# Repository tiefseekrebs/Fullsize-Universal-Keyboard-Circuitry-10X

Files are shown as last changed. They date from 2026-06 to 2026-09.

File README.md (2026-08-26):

# FUKC10X — Fullsize Universal Keyboard Circuitry 10X

> 🚧 **Work in Progress** — This PCB has **not yet been prototyped** and currently has **no firmware**.
---

## Introduction

**Fullsize Universal Keyboard Circuitry 10X or fukc10X for short**, is an open-source, full-size (100%) mechanical keyboard PCB designed in KiCad. It's essentially a Daughterboard only h87 footprint pcb just with a numpad attached.

This came to life after i wanted to design a Fullsize Keyboard but found out there were no modern opensource full-size keyboard pcbs.

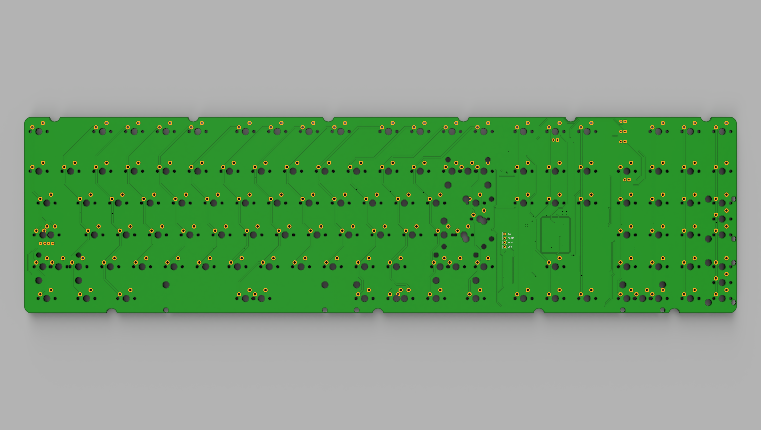
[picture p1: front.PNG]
Render Front

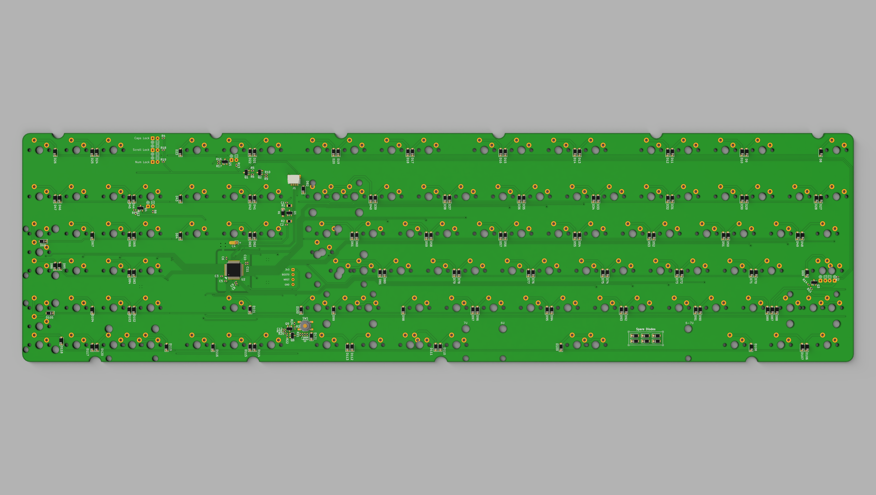
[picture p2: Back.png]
Render Back


---

## Features
- Dual Indicators. You can have indicator leds for Caps Lock, Scroll Lock and Num Lock directly at the switches for the use with windowed Keycaps and above the numpad in a small cluster.
- Decent layout support with ANSI+ISO Enter, split l-Shift, split r-Shift, split Backspace, split numpad Enter, split numpad plus and split numpad minus (just check the diagramm)
- Supported bottomrows are Tsangan **7U** aswell as **6U** bottom row, like the Realforce R1 87U. (*I will not be adding 6.25u bottom row*)

---

##  Design Files

The files were designed in KiCAD 10.0.
This project uses component symbols and footprints from [AlexandriaLibrary](https://github.com/AcheronProject/AlexandriaLibrary) by AcheronProject, licensed under the BSD-3-Clause License.
Furthermore some symbols and footprints from the [marbastlib](https://github.com/ebastler/marbastlib) are used.

---

## Supported Layouts

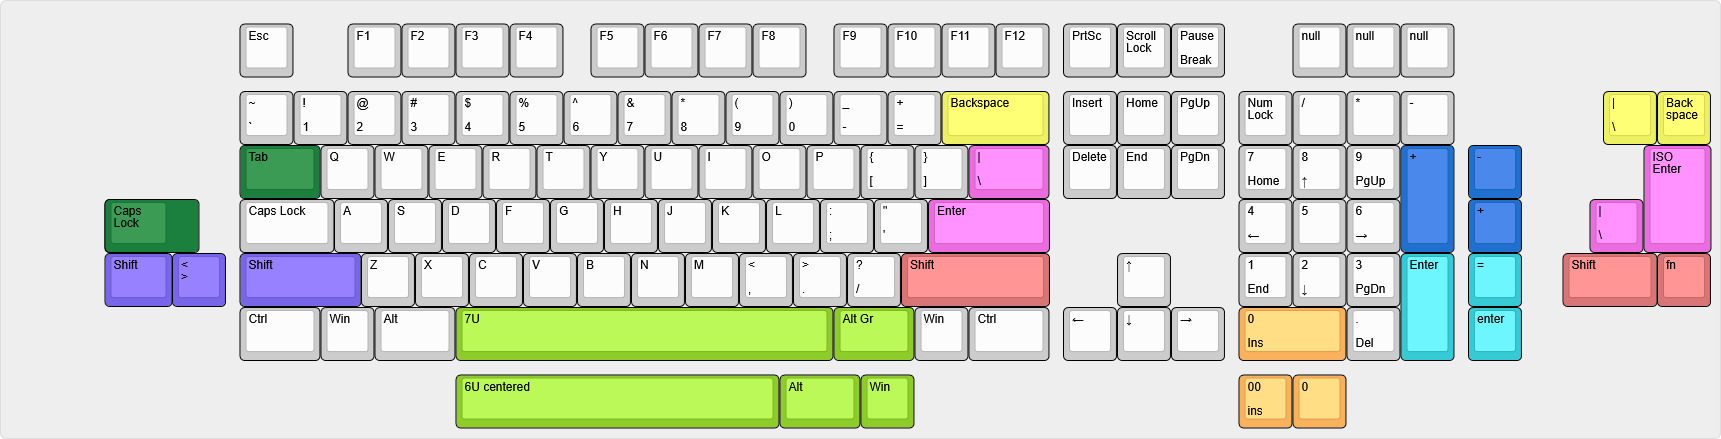
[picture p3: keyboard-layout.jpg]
KLE Layout


---

## Daughterboard Connector

Uses standard 4-pin JST commonly found on all sorts of Keyboard PCBs. Compatible with any daughterboard that follows the [ai03 unified daughterboard standard](https://unified-daughterboard.github.io/#/) pinout.

---

## Firmware

> ⚠️ **Firmware is not yet written.**

| Firmware | Status |
|---|---|
| **[QMK](https://qmk.fm/)** | Planned after i get Prototypes. |
| **[VIAL](https://get.vial.today/)** | Planned after i get Prototypes. |
| **[VIA](https://www.caniusevia.com/)** | Maybe? |

---

## License

This project is licensed under **Creative Commons Attribution-ShareAlike 4.0 International** ([CC BY-SA 4.0](https://creativecommons.org/licenses/by-sa/4.0/deed.en)).
You may share and adapt it, including commercially, with proper attribution.
Modified versions must be distributed under the same license.

---

*This README was written with the help of deepseek-v4-pro because i suck at stuff like this.*

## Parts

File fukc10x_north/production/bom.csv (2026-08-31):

Designator | Footprint | Quantity | Value | LCSC Part #
C1, C2 | 0402 | 2 | 1uF | C52923
C10, C3, C5, C6 | 0402 | 4 | 100n
C11, C8 | 0402 | 2 | 4.7u
C12 | 0402 | 1 | 100nF | C52923
C4 | CP_EIA-3216-10_Kemet-I_Pad1.58x1.35mm_HandSolder | 1 | 10u
C7 | 0402 | 1 | 10uF | C52923
C9 | 0402 | 1 | 10n
D1 | D_SOD-123 | 1 | B5819W-SL
D10, D100, D101, D102, D103, D104, D105, D106, D107, D108, D109, D11, D110, D111, D112, D113, D114, D115, D116, D117, D118, D119, D12, D120, D13, D14, D15, D16, D17, D18, D19, D2, D20, D21, D22, D23, D24, D25, D26, D27, D28, D29, D3, D30, D31, D32, D33, D34, D35, D36, D37, D38, D39, D4, D40, D41, D42, D43, D44, D45, D46, D47, D48, D49, D5, D50, D51, D52, D53, D54, D55, D56, D57, D58, D59, D6, D60, D61, D62, D63, D64, D65, D66, D67, D68, D69, D7, D70, D71, D72, D73, D74, D75, D76, D77, D78, D79, D8, D80, D81, D82, D83, D84, D85, D86, D87, D88, D89, D9, D90, D91, D92, D93, D94, D95, D96, D97, D98, D99 | D_SOD-123 | 119 | 1N4148W | C81598
D121 | D_SOD-123 | 1 | 1N4148
J1 | JST_SH_SM04B-SRSS-TB_1x04-1MP_P1.00mm_Horizontal | 1 | SM04B-SRSS-TB | C160404
J9 | PinHeader_1x4_P2.54mm_Vertical | 1 | Conn_01x04_Pin
Q1 | SOT-23 | 1 | AO3401A
Q2, Q3, Q4, Q5, Q8, Q9 | SOT-23 | 6 | 2N7002
R1, R2 | 0805 | 2 | 100k
R10, R14, R15, R17, R21, R24, R25, R5 | 0402 | 8 | 10k
R11, R12, R16, R26, R6, R9 | 0402 | 6 | 100
R13, R18, R19, R23, R4, R7, R8 | 0402 | 7 | 1k
R20 | 0402 | 1 | 1M
R22 | 0402 | 1 | 100k
R3 | 0402 | 1 | 330k
SW1 | SW_SPST_TL3342 | 1 | SW_SPST
U1 | SOT-23 | 1 | XC6206P332MR | C5446
U2 | LQFP-48_7x7mm_P0.5mm | 1 | STM32F072CBT6 | C81720

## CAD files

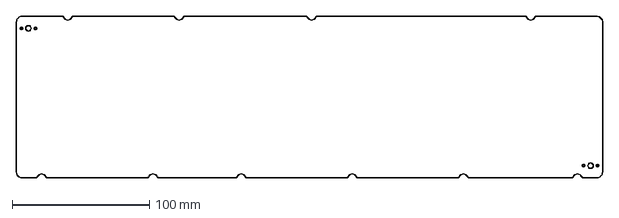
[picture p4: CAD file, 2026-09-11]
fukc10x_north/outline.dxf
427.1 x 117.5 mm

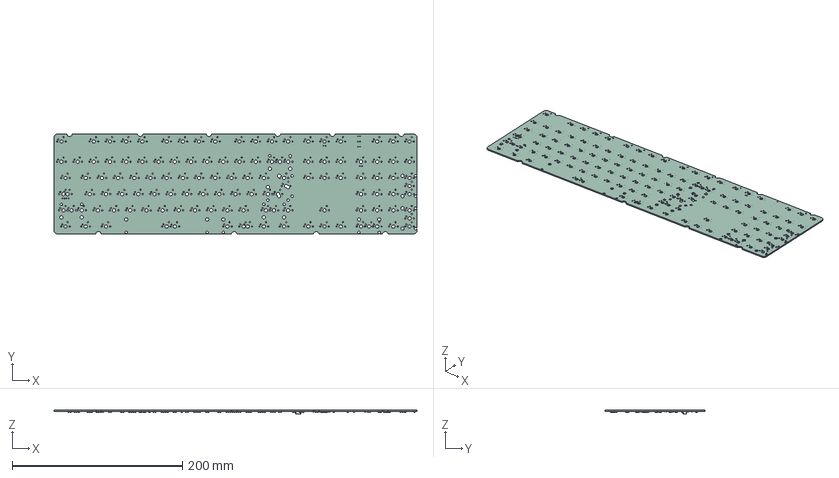
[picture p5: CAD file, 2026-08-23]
fukc10x_north/fukc10X_north.step
427.1 x 117.5 x 4.56 mm
D_SOD-123 x 120
TSOT-23 x 5
R_0402_1005Metric x 15
SW_SPST_TL3342 x 2
C_0402_1005Metric x 10
JST_SH_SM04B-SRSS-TB_1x04-1MP_P1.00mm_Horizontal
SOT-23
CP_EIA-3216-10_Kemet-I
LQFP-48_7x7mm_P0.5mm
R_0805_2012Metric x 2
fukc10x_north_PCB

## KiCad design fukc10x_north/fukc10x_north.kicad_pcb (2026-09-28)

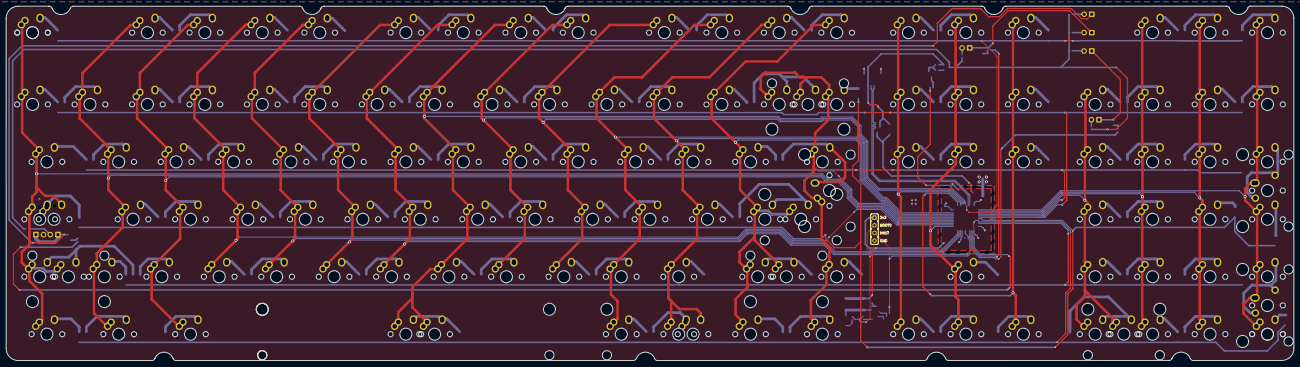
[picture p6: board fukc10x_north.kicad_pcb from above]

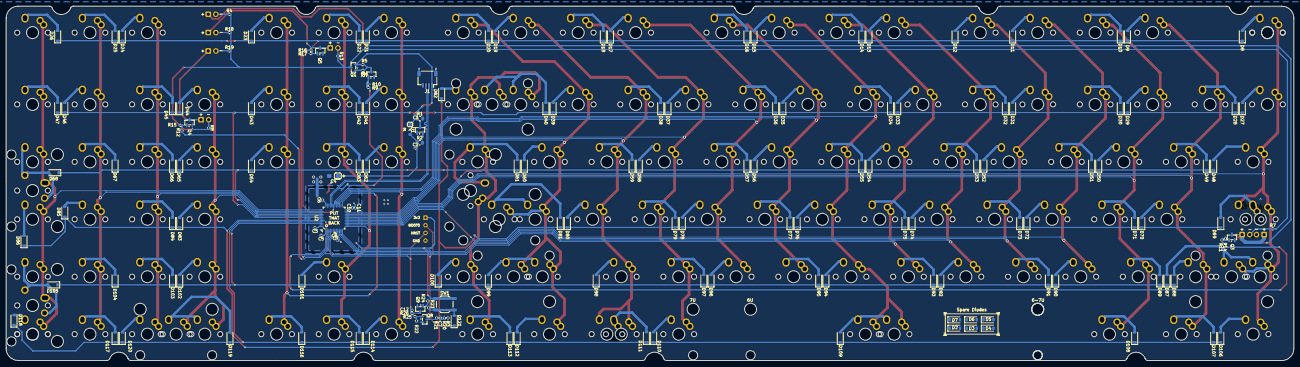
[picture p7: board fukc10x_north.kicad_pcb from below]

Board: 2 copper layers, 427.1 x 117.5 mm, 305 parts (170 on the bottom side), 173 nets.

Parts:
C1, C2: 1uF; C_0402_1005Metric
C3, C5, C6, C10: 100n; C_0402_1005Metric
C4: 10u; CP_EIA-3216-10_Kemet-I_Pad1.58x1.35mm_HandSolder
C7: 10uF; C_0402_1005Metric
C8, C11: 4.7u; C_0402_1005Metric
C9: 10n; C_0402_1005Metric
C12: 100nF; C_0402_1005Metric
D1: B5819W-SL; D_SOD-123
D2, D3, D4, D5, D6, D7, D8, D9, D10, D11, D12, D13, D14, D15, D16, D17, D18, D19, D20, D21, D22, D23, D24, D25, D26, D27, D28, D29, D30, D31, D32, D33, D34, D35, D36, D37, D38, D39, D40, D41, D42, D43, D44, D45, D46, D47, D48, D49, D50, D51, D52, D53, D54, D55, D56, D57, D58, D59, D60, D61, D62, D63, D64, D65, D66, D67, D68, D69, D70, D71, D72, D73, D74, D75, D76, D77, D78, D79, D80, D81, D82, D83, D84, D85, D86, D87, D88, D89, D90, D91, D92, D93, D94, D95, D96, D97, D98, D99, D100, D101, D102, D103, D104, D105, D106, D107, D108, D109, D110, D111, D112, D113, D114, D115, D116, D117, D118, D119, D120: 1N4148W; D_SOD-123
D121: 1N4148; D_SOD-123
J1: SM04B-SRSS-TB; JST_SH_SM04B-SRSS-TB_1x04-1MP_P1.00mm_Horizontal
J2, J3, J4, J5, J8: LED_Conn01x02_Pin; LED_MX_3mm
J6: LED_Conn01x02_Pin; LED_MX_3mm-ROT
J7: LED; LED_MX_3mm
J9: Conn_01x04_Pin; PinHeader_1x4_P2.54mm_Vertical
MX1, MX2, MX3, MX4, MX5, MX6, MX7, MX8, MX9, MX10, MX11, MX12, MX13, MX14, MX15, MX16, MX17, MX18, MX19, MX20, MX21, MX22, MX23, MX24, MX25, MX26, MX27, MX28, MX29, MX30, MX31, MX32, MX33, MX35, MX36, MX37, MX38, MX39, MX40, MX41, MX43, MX44, MX45, MX46, MX47, MX48, MX49, MX50, MX51, MX52, MX53, MX54, MX57, MX58, MX59, MX60, MX61, MX62, MX64, MX67, MX68, MX69, MX70, MX71, MX72, MX73, MX74, MX75, MX76, MX77, MX78, MX80, MX81, MX82, MX83, MX84, MX87, MX88, MX89, MX90, MX91, MX92, MX93, MX94, MX95, MX96, MX97, MX100, MX101, MX102, MX103, MX104, MX106, MX108, MX114, MX115, MX117, MX118, MX119, MX121, MX122, MX123, MX124: MX_SW_solder; MXA100
MX34: MX_SW_solder; MXA250
MX42, MX55, MX107, MX109, MX112, MX113, MX116: MX_SW_solder; MXA150
MX56: MX_SW_solder; MXA_ISO_Enter
MX63, MX105: MX_SW_solder; MX200V
MX65, MX98: MX_SW_solder; MXA175
MX66, MX86: MX_SW_solder; MXA125
MX79: MX_SW_solder; MXA225R
MX85: MX_SW_solder; MXA225
MX99: MX_SW_solder; MXA275
MX110: MX_SW_solder; MXA600R
MX111: MX_SW_solder; MXA700R
MX120: MX_SW_solder; MXA200R
MX125: alps capslock 1.5u; SW_Alps_1.75u_STP_1.5
MX126, MX127: MX_SW_solder; SW_Alps_1u
Q1: AO3401A; SOT-23
Q2, Q3, Q4, Q5, Q8, Q9: 2N7002; SOT-23
R1, R2: 100k; R_0805_2012Metric
R3: 330k; R_0402_1005Metric
R4, R7, R8, R13, R18, R19, R23: 1k; R_0402_1005Metric
R5, R10, R14, R15, R17, R21, R24, R25: 10k; R_0402_1005Metric
R6, R9, R11, R12, R16, R26: 100; R_0402_1005Metric
R20: 1M; R_0402_1005Metric
R22: 100k; R_0402_1005Metric
SW1: SW_SPST; SW_SPST_TL3342
U1: XC6206P332MR; SOT-23
U2: STM32F072CBT6; LQFP-48_7x7mm_P0.5mm

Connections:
+3V3: C2.2, C3.1, C4.1, C5.1, C6.1, C8.2, C9.2, C10.2, C11.1, D1.2 (A), J9.1, R2.1, SW1.1 (A), U1.2 (VO), U2.1 (VBAT), U2.9 (VDDA), U2.24 (VDD), U2.36 (VDDIO2), U2.48 (VDD)
+5V: C1.1, D1.1 (K), J1.1, Q1.2 (S), R1.1, R5.2, U1.3 (VI)
BOOT0: C7.1, J9.2, R3.2, R20.1, R21.1, U2.44 (BOOT0)
COL0: MX1.2, MX20.2, MX42.2, MX65.1, MX66.2, MX85.2, MX86.2, MX107.2, MX125.2, U2.17 (PA7/TIM3_CH2/TIM14_CH1/ADC_IN7)
COL1: MX2.2, MX21.2, MX43.2, MX67.2, MX87.2, MX108.2, U2.16 (PA6/ADC_IN6/TIM3_CH1/TIM16_CH1)
COL2: MX3.2, MX22.2, MX44.2, MX68.2, MX88.2, MX109.2, U2.15 (PA5/ADC_IN5/DAC_OUT2)
COL3: MX4.2, MX23.2, MX45.2, MX69.2, MX89.2, U2.14 (PA4/TIM14_CH1/ADC_IN4)
COL4: MX5.2, MX24.2, MX46.2, MX70.2, MX90.2, U2.12 (PA2/ADC_IN2)
COL5: MX6.2, MX25.2, MX47.2, MX71.2, MX91.2, U2.11 (PA1/ADC_IN1)
COL6: MX7.2, MX26.2, MX48.2, MX72.2, MX92.2, U2.10 (PA0/ADC_IN0)
COL7: MX8.2, MX27.2, MX49.2, MX73.2, MX93.2, MX110.2, MX111.2, U2.29 (TIM1_CH1/PA8)
COL8: MX9.2, MX28.2, MX50.2, MX74.2, MX94.2, U2.28 (SPI2_MOSI/I2S2_SD/PB15)
COL9: MX10.2, MX29.2, MX51.2, MX75.2, MX95.2, U2.22 (PB11/TIM2_CH4/I2C2_SDA)
COL10: MX11.2, MX30.2, MX52.2, MX76.2, MX96.2, MX112.2, U2.21 (PB10/SPI2_SCK/I2C2_SCL/TIM2_CH3)
COL11: MX12.2, MX31.2, MX53.2, MX77.2, MX97.2, MX113.2, MX114.1, U2.20 (PB2)
COL12: MX13.2, MX32.2, MX54.2, MX78.2, MX79.2, MX98.2, MX99.2, MX115.2, U2.19 (PB1/TIM3_CH4/TIM14_CH1/ADC_IN9)
COL13: MX33.2, MX34.2, MX55.2, MX56.2, MX80.2, MX100.2, MX116.2, U2.18 (PB0/TIM3_CH3/ADC_IN8)
COL14: MX14.2, MX35.2, MX57.2, MX117.2, U2.27 (SPI2_MISO/I2S2_MCK/I2C2_SDA/TIM15_CH1/P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)
COL15: MX15.2, MX36.2, MX58.2, MX101.2, MX118.2, U2.13 (PA3/TIM15_CH2/ADC_IN3)
COL16: MX16.2, MX37.2, MX59.2, MX119.2, U2.25 (PB12)
COL17: MX38.2, MX60.2, MX81.2, MX102.2, MX120.2, MX123.2, U2.40 (SPI1_MISO/I2S1_MCK/TIM3_CH1/PB4)
COL18: MX17.2, MX39.2, MX61.2, MX82.2, MX103.2, MX124.2, U2.39 (SPI1_SCK/I2S1_CK/TIM2_CH2/PB3)
COL19: MX18.2, MX40.2, MX62.2, MX83.2, MX104.2, MX121.2, U2.38 (PA15)
COL20: MX19.2, MX41.2, MX63.2, MX64.2, MX84.2, MX105.2, MX106.2, MX122.2, MX126.2, MX127.2, U2.37 (SWCLK/PA14)
D+: J1.3, U2.33 (USB_DP/PA12)
D-: J1.2, U2.32 (USB_DM/TIM1_CH4/PA11)
GND: C1.2, C2.1, C3.2, C4.2, C5.2, C6.2, C7.2, C8.1, C9.1, C10.1, C11.2, C12.2, J1.4, J1.MP (MountPin), J9.4, Q2.2 (S), Q3.2 (S), Q4.2 (S), Q5.2 (S), Q8.2 (S), Q9.2 (S), R1.2, R2.2, R10.1, R14.1, R15.1, R17.1, R20.2, R22.2, R24.1, U1.1 (GND), U2.8 (VSSA), U2.23 (VSS), U2.35 (VSS), U2.47 (VSS)
LED_PWM: R9.1, U2.30 (TIM1_CH2/PA9)
LED_PWM_OUT: Q1.3 (D), R4.2, R7.2, R8.2, R13.2, R18.2, R19.2
LedCaps: R11.1, U2.2 (PC13)
LedNum: R12.1, U2.4 (PC15/OSC32_OUT)
LedScroll: R16.1, U2.3 (PC14/OSC32_IN)
NRST: C12.1, J9.3, R26.2, U2.7 (NRST)
unnamed: D8.2 (A), MX1.1
unnamed: D9.2 (A), MX2.1
unnamed: D10.2 (A), MX3.1
unnamed: D11.2 (A), MX4.1
unnamed: D12.2 (A), MX5.1
unnamed: D13.2 (A), MX6.1
unnamed: D14.2 (A), MX7.1
unnamed: D15.2 (A), MX8.1
unnamed: D16.2 (A), MX9.1
unnamed: D17.2 (A), MX10.1
unnamed: D18.2 (A), MX11.1
unnamed: D19.2 (A), MX12.1
unnamed: D20.2 (A), MX13.1
unnamed: D21.2 (A), MX14.1
unnamed: D22.2 (A), MX15.1
unnamed: D23.2 (A), MX16.1
unnamed: D24.2 (A), MX17.1
unnamed: D25.2 (A), MX18.1
unnamed: D26.2 (A), MX19.1
unnamed: D27.2 (A), MX20.1
unnamed: D28.2 (A), MX21.1
unnamed: D29.2 (A), MX22.1
unnamed: D30.2 (A), MX23.1
unnamed: D31.2 (A), MX24.1
unnamed: D32.2 (A), MX25.1
unnamed: D33.2 (A), MX26.1
unnamed: D34.2 (A), MX27.1
unnamed: D35.2 (A), MX28.1
unnamed: D36.2 (A), MX29.1
unnamed: D37.2 (A), MX30.1
unnamed: D38.2 (A), MX31.1
unnamed: D39.2 (A), MX32.1
unnamed: D40.2 (A), MX33.1, MX34.1
unnamed: D41.2 (A), MX35.1
unnamed: D42.2 (A), MX36.1
unnamed: D43.2 (A), MX37.1
unnamed: D44.2 (A), MX38.1
unnamed: D45.2 (A), MX39.1
unnamed: D46.2 (A), MX40.1
unnamed: D47.2 (A), MX41.1
unnamed: D48.2 (A), MX42.1
unnamed: D49.2 (A), MX43.1
unnamed: D50.2 (A), MX44.1
unnamed: D51.2 (A), MX45.1
unnamed: D52.2 (A), MX46.1
unnamed: D53.2 (A), MX47.1
unnamed: D54.2 (A), MX48.1
unnamed: D55.2 (A), MX49.1
unnamed: D56.2 (A), MX50.1
unnamed: D57.2 (A), MX51.1
unnamed: D58.2 (A), MX52.1
unnamed: D59.2 (A), MX53.1
unnamed: D60.2 (A), MX54.1
unnamed: D61.2 (A), MX55.1, MX56.1
unnamed: D62.2 (A), MX57.1
unnamed: D63.2 (A), MX58.1
unnamed: D64.2 (A), MX59.1
unnamed: D65.2 (A), MX60.1
unnamed: D66.2 (A), MX61.1
unnamed: D67.2 (A), MX62.1
unnamed: D68.2 (A), MX63.1, MX64.1, MX126.1
unnamed: D69.2 (A), MX65.2, MX66.1, MX125.1
unnamed: D70.2 (A), MX67.1
unnamed: D71.2 (A), MX68.1
unnamed: D72.2 (A), MX69.1
unnamed: D73.2 (A), MX70.1
unnamed: D74.2 (A), MX71.1
unnamed: D75.2 (A), MX72.1
unnamed: D76.2 (A), MX73.1
unnamed: D77.2 (A), MX74.1
unnamed: D78.2 (A), MX75.1
unnamed: D79.2 (A), MX76.1
unnamed: D80.2 (A), MX77.1
unnamed: D81.2 (A), MX78.1, MX79.1
unnamed: D82.2 (A), MX80.1
unnamed: D83.2 (A), MX81.1
unnamed: D84.2 (A), MX82.1
unnamed: D85.2 (A), MX83.1
unnamed: D86.2 (A), MX84.1
unnamed: D87.2 (A), MX85.1, MX86.1
unnamed: D88.2 (A), MX87.1
unnamed: D89.2 (A), MX88.1
unnamed: D90.2 (A), MX89.1
unnamed: D91.2 (A), MX90.1
unnamed: D92.2 (A), MX91.1
unnamed: D93.2 (A), MX92.1
unnamed: D94.2 (A), MX93.1
unnamed: D95.2 (A), MX94.1
unnamed: D96.2 (A), MX95.1
unnamed: D97.2 (A), MX96.1
unnamed: D98.2 (A), MX97.1
unnamed: D99.2 (A), MX98.1, MX99.1
unnamed: D100.2 (A), MX100.1
unnamed: D101.2 (A), MX101.1
unnamed: D102.2 (A), MX102.1
unnamed: D103.2 (A), MX103.1
unnamed: D104.2 (A), MX104.1
unnamed: D105.2 (A), MX105.1, MX106.1, MX127.1
unnamed: D106.2 (A), MX107.1
unnamed: D107.2 (A), MX108.1
unnamed: D108.2 (A), MX109.1
unnamed: D109.2 (A), MX110.1, MX111.1
unnamed: D110.2 (A), MX112.1
unnamed: D111.2 (A), MX113.1, MX114.2
unnamed: D112.2 (A), MX115.1
unnamed: D113.2 (A), MX116.1
unnamed: D114.2 (A), MX117.1
unnamed: D115.2 (A), MX118.1
unnamed: D116.2 (A), MX119.1
unnamed: D117.2 (A), MX121.1
unnamed: D118.2 (A), MX122.1
unnamed: D119.2 (A), MX120.1, MX123.1
unnamed: D120.2 (A), MX124.1
unnamed: D121.2 (A), R23.2, SW1.2 (B)
unnamed: D121.1 (K), R3.1
unnamed: J2.2 (A), R4.1
unnamed: J2.1 (K), J6.1 (K), J7.1 (K), Q3.3 (D)
unnamed: J3.2 (A), R18.1
unnamed: J3.1 (K), J8.1 (K), Q5.3 (D)
unnamed: J4.2 (A), R19.1
unnamed: J4.1 (K), J5.1 (K), Q4.3 (D)
unnamed: J5.2 (A), R8.1
unnamed: J6.2 (A), J7.2 (A), R7.1
unnamed: J8.2 (A), R13.1
unnamed: Q1.1 (G), R6.2
unnamed: Q2.3 (D), R5.1, R6.1
unnamed: Q2.1 (G), R9.2, R10.2
unnamed: Q3.1 (G), R11.2, R14.2
unnamed: Q4.1 (G), R12.2, R15.2
unnamed: Q5.1 (G), R16.2, R17.2
unnamed: Q8.3 (D), R21.2
unnamed: Q8.1 (G), R22.1, R25.1
unnamed: Q9.3 (D), R25.2, R26.1
unnamed: Q9.1 (G), R23.1, R24.2
ROW0: D8.1 (K), D9.1 (K), D10.1 (K), D11.1 (K), D12.1 (K), D13.1 (K), D14.1 (K), D15.1 (K), D16.1 (K), D17.1 (K), D18.1 (K), D19.1 (K), D20.1 (K), D21.1 (K), D22.1 (K), D23.1 (K), D24.1 (K), D25.1 (K), D26.1 (K), U2.31 (TIM1_CH3/PA10)
ROW1: D27.1 (K), D28.1 (K), D29.1 (K), D30.1 (K), D31.1 (K), D32.1 (K), D33.1 (K), D34.1 (K), D35.1 (K), D36.1 (K), D37.1 (K), D38.1 (K), D39.1 (K), D40.1 (K), D41.1 (K), D42.1 (K), D43.1 (K), D44.1 (K), D45.1 (K), D46.1 (K), D47.1 (K), U2.42 (I2C1_SCL/PB6)
ROW2: D48.1 (K), D49.1 (K), D50.1 (K), D51.1 (K), D52.1 (K), D53.1 (K), D54.1 (K), D55.1 (K), D56.1 (K), D57.1 (K), D58.1 (K), D59.1 (K), D60.1 (K), D61.1 (K), D62.1 (K), D63.1 (K), D64.1 (K), D65.1 (K), D66.1 (K), D67.1 (K), D68.1 (K), U2.41 (SPI1_MOSI/I2S1_SD/TIM3_CH2/PB5)
ROW3: D69.1 (K), D70.1 (K), D71.1 (K), D72.1 (K), D73.1 (K), D74.1 (K), D75.1 (K), D76.1 (K), D77.1 (K), D78.1 (K), D79.1 (K), D80.1 (K), D81.1 (K), D82.1 (K), D83.1 (K), D84.1 (K), D85.1 (K), D86.1 (K), U2.43 (2C1_SDA/PB7)
ROW4: D87.1 (K), D88.1 (K), D89.1 (K), D90.1 (K), D91.1 (K), D92.1 (K), D93.1 (K), D94.1 (K), D95.1 (K), D96.1 (K), D97.1 (K), D98.1 (K), D99.1 (K), D100.1 (K), D101.1 (K), D102.1 (K), D103.1 (K), D104.1 (K), D105.1 (K), U2.46 (SPI2_NSS/I2S2_WS/I2C1_SDA/TIM17_CH1/PB9)
ROW5: D106.1 (K), D107.1 (K), D108.1 (K), D109.1 (K), D110.1 (K), D111.1 (K), D112.1 (K), D113.1 (K), D114.1 (K), D115.1 (K), D116.1 (K), D117.1 (K), D118.1 (K), D119.1 (K), D120.1 (K), U2.45 (I2C1_SCL/TIM16_CH1/PB8)

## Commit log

2026-06-07 Add PCB files
    [FullsizeKeyboardPCB.kicad_sch, bom.csv, designators.csv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]
2026-06-07 Add PCB files again
    [FullsizeKeyboardPCB.kicad_sch, bom.csv, designators.csv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]
2026-06-07 further cleanup
    [oh10x_simple.step]
2026-06-08 Extended Matrix. Added split r-shift and split l-shift. LED support. Removed three of the 4 top right keys because ugly and to make space for indicator leds there
    [fukc10X.kicad_sch, fukc10X.step, matrix.kicad_sch]
2026-06-08 Added some Silkscreen Text aswell as spare diodes
    [fukc10X.kicad_sch, fukc10X.step]
2026-06-09 Diodes moved, ISO enter added, Som Silkscreens moved aswell. Generally some cleanup
    [matrix.kicad_sch]
2026-06-11 added split backspace + some updates to the matrix
    [bom.csv, designators.csv, fukc10X.kicad_sch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]
2026-06-13 silkscreen adjustment. 87U bottom row with 6u spacebar added.
    [bom.csv, designators.csv, matrix.kicad_sch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]
2026-06-15 adjusted spare diodes and some rounting. Updated step and production files
    [bom.csv, designators.csv, fukc10X.kicad_pcb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]
2026-06-17 updated LED Symbols + removed unnessecarry components for ESD and fusing
    [fukc10X.kicad_pcb, fukc10X.kicad_sch]
2026-06-18 added back keys above numpad + updated step file/prod stuff
    [bom.csv, designators.csv, fukc10X.kicad_pcb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]
2026-06-20 Soutfacing spacebar + zero Diode moved
    [fukc10X.kicad_pcb, fukc10X.step]
2026-06-20 render, neue step dateien
    [fukc10X.kicad_pcb, fukc10X.step]
2026-06-23 south and north variant
    [bom.csv, designators.csv, fukc10X.kicad_pcb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]
2026-06-23 update directorys
    [bom.csv, designators.csv, fukc10X.kicad_pcb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]
2026-06-23 update prod data
    [fukc10x_north.kicad_pcb, fukc10x_south.kicad_pcb, positions.csv]
2026-06-23 moved forgotten leds
    [fukc10X_north.step, fukc10X_south.step, fukc10x_north.kicad_pcb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]
2026-07-26 south version currently depreciated. Slight outline errors fixed on north version, aswell as traces adjusted/diodes moved to allow for shims when used with 1.2mm thickness. Indicator led were also ev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
    [bom.csv, designators.csv, fukc10X_south.step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]
2026-07-26 south version no longer depreciated
    [bom.csv, designators.csv, fukc10X_north.step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]
2026-08-11 updated some traces/routing
    [fukc10x_north.kicad_pcb]
2026-08-11 updated parts for bom and stuff
    [fukc10x_north.kicad_pcb, fukc10x_north.kicad_sch, matrix.kicad_sch]
2026-08-16 After feedback from gondo draining resistors and a crowbar diode added. Symbol for mcu changed to one from acheron project. Power/ground planes adjusted and added island around MCU for power and grou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
    [fukc10x_north.kicad_pcb, fukc10x_north.kicad_sch]
2026-08-16 fixed some routing, changed footprints from marbastler to acheron alexandria lib (although with rotated switches(kinda cursed))
    [bom.csv, designators.csv, fukc10X_south.step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]
2026-08-16 fixed some shenanaigans
    [fukc10x_north.kicad_pcb, matrix.kicad_sch]
2026-08-19 added library, fixed some routing and LED stuff
    [fukc10x_north.kicad_pcb, fukc10x_north.kicad_sch, matrix.kicad_sch]
2026-08-22 changed some traces and stuff
    [fukc10x_north.kicad_pcb]
2026-08-23 adjusted some traces, fixed some stuff for the leds. Reset and boot circutry still pending. Full DRC ran and mostly fixed
    [fukc10X_north.step, fukc10x_north.kicad_pcb, fukc10x_north.kicad_sch]
2026-08-26 adjusted some traces, flipped some switches, went through drc again
    [fukc10x_north.kicad_pcb, fukc10x_north.kicad_sch, matrix.kicad_sch]
2026-08-26 cleanup and picture update
    [fukc10x_sout outline.step, south outline.dxf]
2026-08-31 updated some stuff/small trace adjustments
    [bom.csv, designators.csv, fukc10x_north.kicad_pcb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]
2026-09-09 changed to mx alps footprints. Alexandria footrpints were edited for this putpose. Added those footprint to the library folder
    [fukc10x_north.kicad_pcb, matrix.kicad_sch]
2026-09-11 cursed alps capslock added (1.5u w step) added outline dxf
    [fukc10x_north.kicad_pcb, matrix.kicad_sch, outline.dxf]
2026-09-12 changed vertical 2us on numpad. MX and alps switches for those are now separat footprints to make routing easier and not have cursed vertical mx switches. Adjustes some traces and so on. alps footpri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
    [fukc10x_north.kicad_pcb, matrix.kicad_sch]
2026-09-13 i hate diode silksceens
    [fukc10x_north.kicad_pcb]
2026-09-28 finishing touches (hopefully)
    [fukc10x_north.kicad_pcb, matrix.kicad_sch]
2026-11-07 Added additional Key top right For Compatibility purposes. Planning on adding F13 support aswell as adjusting the outline to hopefully also include cutouts and such to allow for compatibility with ot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
2026-11-07 F13 support. Slight matrix re-wire due to it
2026-11-11 outline updated. Option for onboard USB-C at the h87 position added. Option for integrated cable added with cable tiedown points. USB ESD and Fuse added + some re-routing of the 5v. Fuse sits behind 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
2026-11-13 Fixed some issues with 3d Models, moved some silkscreens around, added some renders and a .pcb3d file (See pcb2blender how to import it into Blender). Boot and reset have been reverted to be separate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
